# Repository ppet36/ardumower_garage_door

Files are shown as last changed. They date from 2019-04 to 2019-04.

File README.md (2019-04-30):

# ArduMower electric garage door

This repository contains resources for my electric garage door for ArduMower. I created them because cats and other animals went to the garage and left the products of their digestive tract in it :)

Used motor is UXCELL 30RPM 24V motor (https://www.ebay.com/itm/DC-24V-30RPM-8mmx15mm-Dual-D-Shape-Shaft-Electric-Power-Turbo-Worm-Geared-Motor/362278845277).

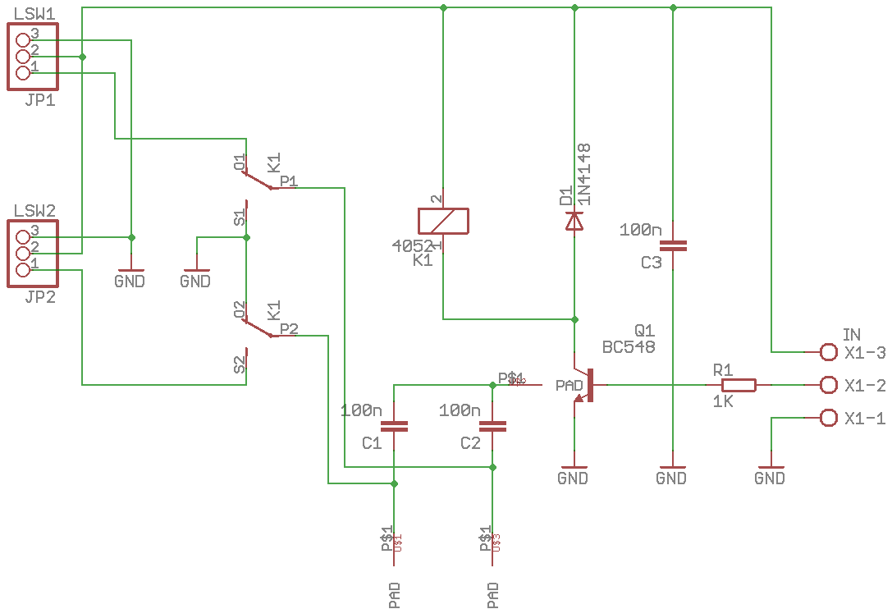
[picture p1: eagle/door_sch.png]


Pad between two 100n capacitors is connected directly to the chassis of motor to avoid interference. PCB is mounted on motor with four M4 screws.

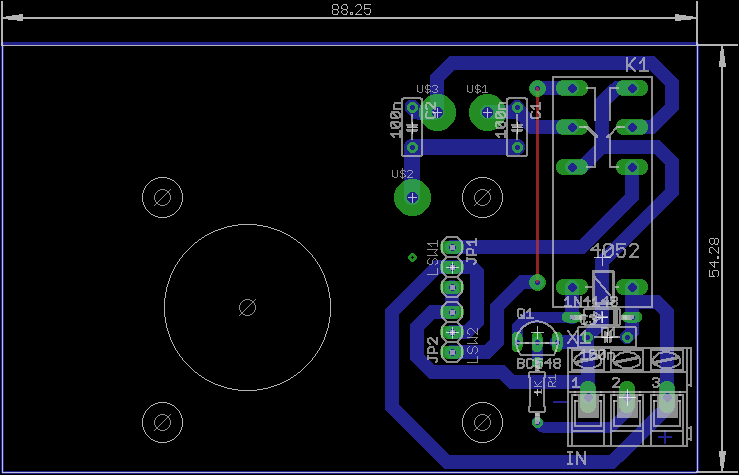
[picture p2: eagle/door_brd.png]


Extra space (top/left) around motor is used for mounting micro-switches at desired position.

Door in the action can be seen on YouTube https://youtu.be/0yKCrzkIeTo

Signal pin is connected to perimeter sender. When sender is ON (mower is mowing) door is open. If mower is in garage eq. charging and perimeter sender is OFF, door is closed. Signal is connected on pin D10 a firmware of perimeter sender slightly modified to control pin.

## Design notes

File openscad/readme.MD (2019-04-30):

M4 spacer to mount motor to PCB. I printed it from PET.

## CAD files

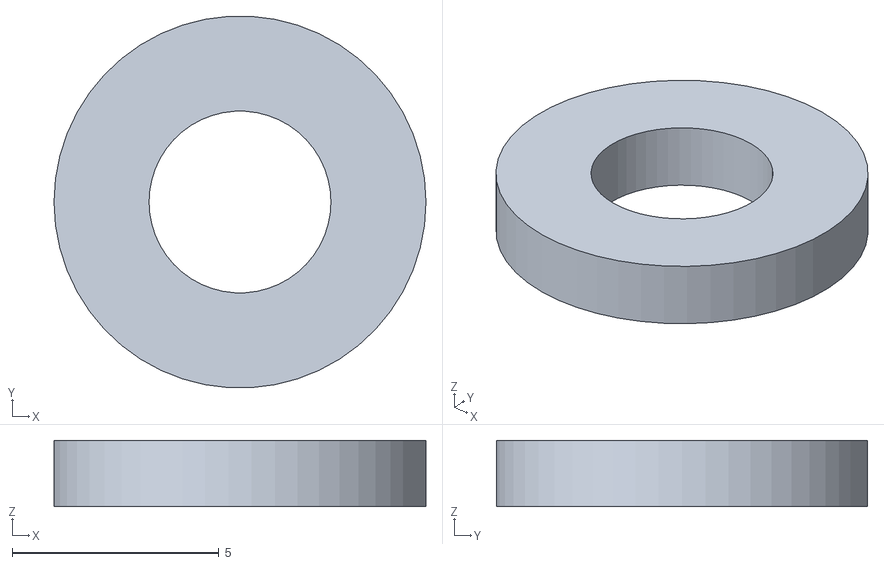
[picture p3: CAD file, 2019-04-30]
openscad/podlozka_m4.stl
9.00 x 8.98 x 1.60

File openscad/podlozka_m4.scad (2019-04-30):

$fn=50;

difference() {
  cylinder (d=9, h=1.6, center=true);
  cylinder (d=4.4, h=1.7, center=true);
}

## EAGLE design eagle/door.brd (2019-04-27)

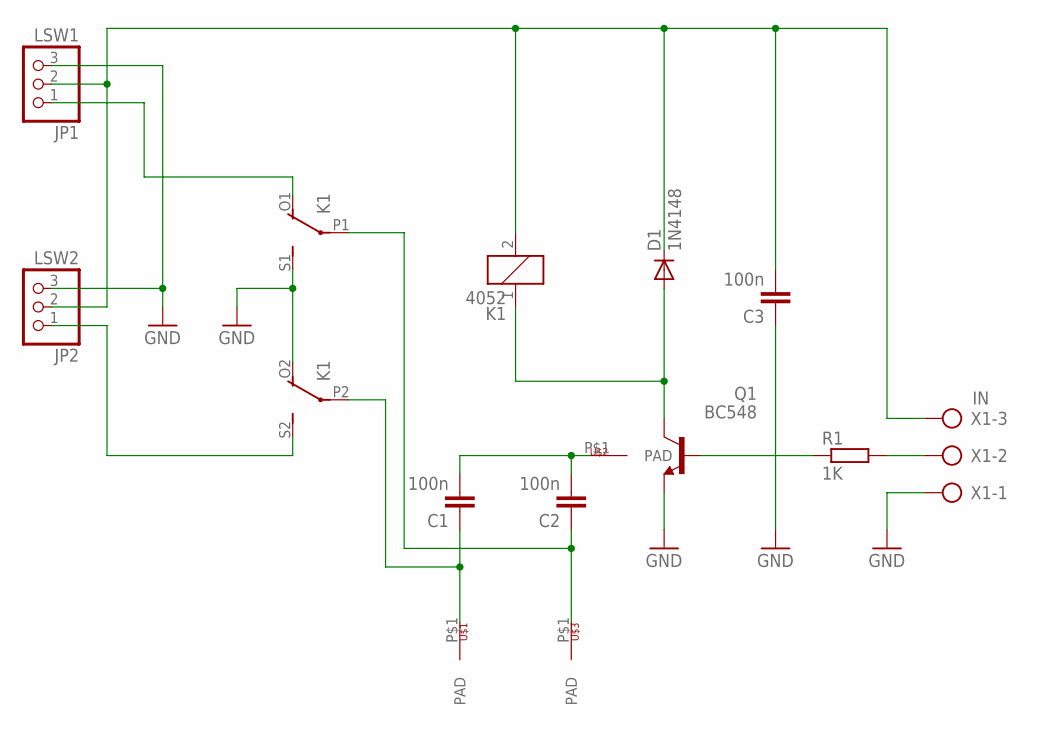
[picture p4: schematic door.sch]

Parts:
C1, C2, C3: 100n; C050-025X075
D1: 1N4148; DO35-7
JP1: LSW1; 1X03
JP2: LSW2; 1X03
K1: 4052; F4052
Q1: BC548; TO92-EBC
R1: 1K; 0204/7
U$1, U$2, U$3: PAD
X1: IN; AK300/3

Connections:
+24VDC: C3.2, D1.C, JP1.2, JP2.2, K1.2, X1.3
DRIVE: R1.2, X1.2
GND: C3.1, JP1.3, JP2.3, K1.O2 (O), K1.S1 (S), Q1.E, X1.1
unnamed: D1.A, K1.1, Q1.C
unnamed: Q1.B, R1.1
unnamed: JP2.1, K1.S2 (S)
unnamed: C2.1, K1.P1, U$3.P$1
unnamed: C1.1, K1.P2, U$1.P$1
unnamed: C1.2, C2.2, U$2.P$1
unnamed: JP1.1, K1.O1 (O)

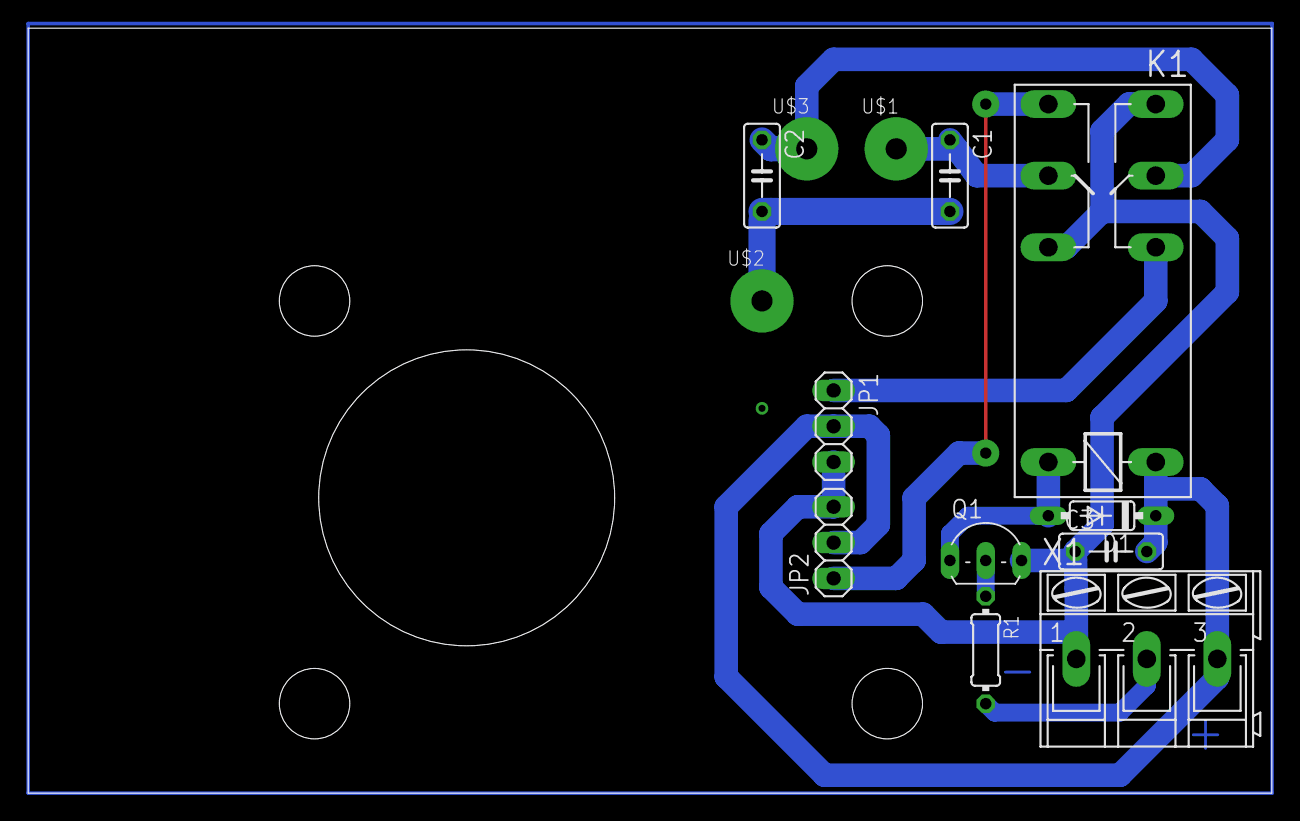
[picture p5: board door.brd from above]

Board: 2 copper layers, 88.2 x 54.3 mm, 13 parts (0 on the bottom side), 10 nets.
